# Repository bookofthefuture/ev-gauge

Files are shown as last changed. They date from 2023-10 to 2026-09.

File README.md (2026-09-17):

# ev-gauge
SoC, motor amps, motor/pack temp, 12V aux voltage, car mode and Zombieverter error
data over CANbus, on a single mode-aware display. For ESP32.

Copy `ev_gauge/secrets.h.example` to `ev_gauge/secrets.h` and fill in your home WiFi
SSID/password before flashing - the gauge runs its own `gaugedriver` AP and joins that
network at the same time, so OTA updates work both standalone and from your desk.

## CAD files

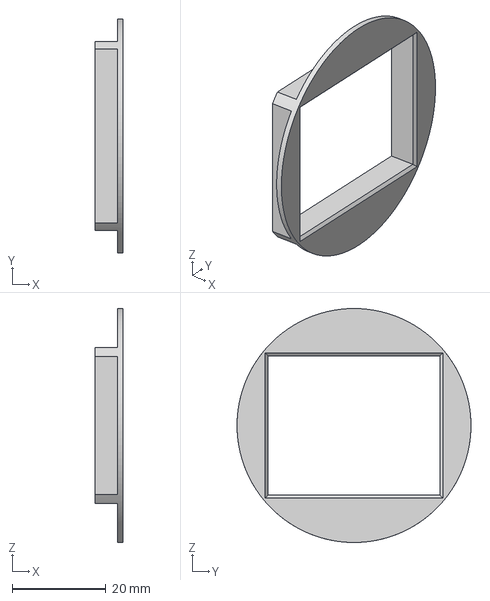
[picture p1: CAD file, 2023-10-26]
3D Files/z3_display_adaptor_front.3mf
6.00 x 50.0 x 50.0 mm

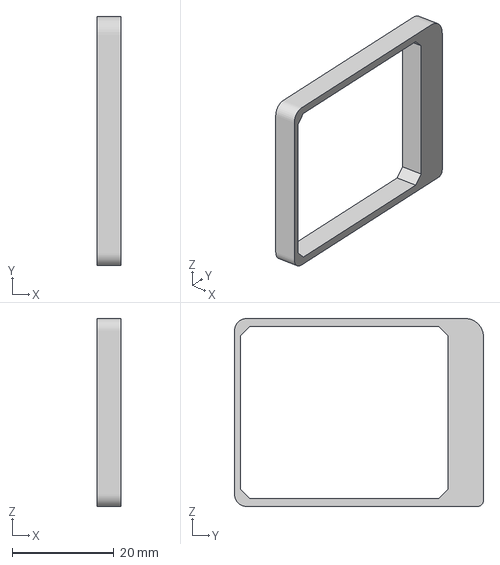
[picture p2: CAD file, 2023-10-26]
3D Files/z3_display_adaptor_rear.3mf
4.80 x 49.0 x 37.0 mm

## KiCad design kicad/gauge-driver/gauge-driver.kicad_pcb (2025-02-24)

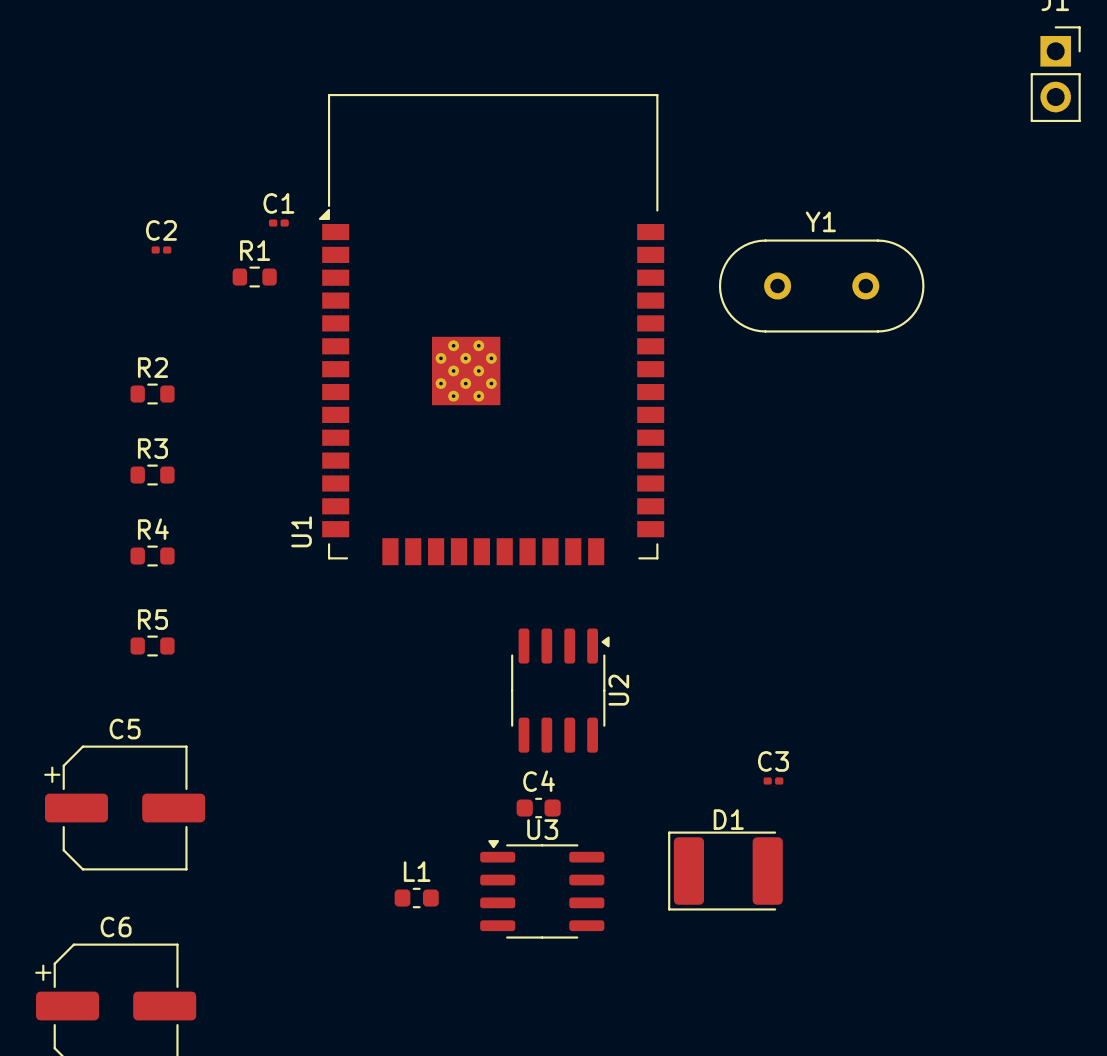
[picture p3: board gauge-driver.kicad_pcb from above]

Board: 2 copper layers, 18 parts (0 on the bottom side), 14 nets, no tracks yet.

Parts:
C1: 22uF; C_0201_0603Metric
C2: 0.1uF; C_0201_0603Metric
C3: 1uF; C_0201_0603Metric
C4: C; C_0603_1608Metric
C5, C6: C_Polarized; CP_Elec_6.3x3
D1: D_Schottky; D_2114_3652Metric
J1: Conn_01x02_Socket; PinSocket_1x02_P2.54mm_Vertical
L1: L; L_0603_1608Metric
R1: 10k; R_0603_1608Metric
R2, R3, R4: R; R_0603_1608Metric
R5: 10K; R_0603_1608Metric
U1: ESP32-WROOM-32E; ESP32-WROOM-32D
U2: SN65HVD230; SOIC-8_3.9x4.9mm_P1.27mm
U3: LM2675M-3.3; SOIC-8_3.9x4.9mm_P1.27mm
Y1: Crystal; Crystal_HC18-U_Vertical

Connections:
/3v3: C1.1, C2.1, R1.1, U1.2 (VDD)
/CAN0_RXD: U1.24 (IO2), U2.4 (R)
/CAN0_TXD: U1.23 (IO15), U2.1 (D)
/Vin_12V: C5.1, U3.7 (VIN)
/Vout_3v3: C6.1, L1.2, U3.4 (FB)
GND: C1.2, C2.2, C3.2, C5.2, C6.2, D1.2 (A), R2.2, R3.2, R4.1, R4.2, R5.2, U1.1 (GND), U1.15 (GND), U1.38 (GND), U1.39 (GND), U2.2 (GND), U3.6 (GND), Y1.1, Y1.2
unnamed: C4.2, D1.1 (K), L1.1, U3.8 (VSW)
unnamed: J1.1, U2.7 (CANH)
unnamed: J1.2, U2.6 (CANL)
unnamed: C3.1, R1.2, U1.3 (EN)
unnamed: R2.1, U1.8 (IO32)
unnamed: R3.1, U1.9 (IO33)
unnamed: R5.1, U2.8 (Rs)
unnamed: C4.1, U3.1 (CB)

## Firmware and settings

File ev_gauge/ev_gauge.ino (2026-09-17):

/* Canbus-powered information gauge for DIY EV. Designed for Adafruit 1.8in screen powered by ST7735 driver board.
 * Uses SN65HVD canbus transceiver with ESP32 onboard can
 * OTA updating for software in case the driver is buried in your dash
 * Reads SoC, pack temp, cell delta, motor current, motor temp, 12V aux voltage, car mode,
 * error codes and heater status from Zombieverter-mapped CAN signals (see the CanSignal
 * table and CAN_ID_HEATER below - these CAN IDs are placeholders and MUST be filled in with
 * your Zombieverter CAN map before flashing). The heater sits on its own CAN bus on the far
 * side of Zombieverter, so it's only visible here via Zombieverter's mapping too, same as
 * the battery/motor signals.
 * Display layout changes with car mode (On / Running / Charging) - see drawModeLayout().
 * Single physical display (tft1) - a second display was previously wired in software but
 * never actually installed, so that code has been removed.
*/

//Include libraries for display, OTA and can communications
#include <WiFi.h>
#include <WiFiClient.h>
#include <AsyncTCP.h> //
#include <ESPAsyncWebServer.h>
#include <Adafruit_GFX.h>    // Core graphics library https://github.com/adafruit/Adafruit-GFX-Library
#include <Adafruit_ST7735.h> // Hardware-specific library for ST7735 https://github.com/adafruit/Adafruit-ST7735-Library
#include <SPI.h>
#include <Arduino.h>
#include <esp32_can.h> // ESP32 native can library
#include <ElegantOTA.h> //Note: uses library in Async mode. Check documentation here: https://docs.elegantota.pro/async-mode/. Modification needed to library for this to work.
#include <SPIFFS.h>
#include <SPIFFS_ImageReader.h> // https://github.com/lucadentella/SPIFFS_ImageReader
#include <TaskScheduler.h> // https://github.com/arkhipenko/TaskScheduler
#include <math.h>

// Image reader
SPIFFS_ImageReader reader;

//#define DEBUG

// OTA CONFIG
const char* ssid = "gaugedriver"; // always-on AP, used as a fallback when not on HOME_WIFI_SSID
const char* password = "123456789";
#include "secrets.h" // HOME_WIFI_SSID / HOME_WIFI_PASSWORD - gitignored, see secrets.h.example

unsigned long ota_progress_millis = 0;

// HEATER DATA
bool hvPresent = false;
bool heater_enabled = false;
bool heating = false;

unsigned char heater_temp = 0;
unsigned char heater_target = 0;
unsigned long heaterTargetChangedAt = 0;

// Web interface
AsyncWebServer server(80);

// Include fonts for display
#include <Fonts/FreeSansBold12pt7b.h>
#include <Fonts/FreeSansBold18pt7b.h>
#include <Fonts/FreeSansBold24pt7b.h>
#include "ev_diy_font.h"


// Configure i2c pins for display - 30 pin layout
// Note change of layout to make wiring simpler

//BLK (backlight) connect to 3v3 output
//3v3
//GND
#define TFT_RST        25
#define TFT_SDA        26
#define TFT_SCL        27
#define TFT_DC         33
#define TFT_1_CS       14
#define TFT_1_BLK      19

// PWM for controlling display brightness
const int TFT_FREQ = 5000;
const int TFT_1_BLK_CHAN = 0;
const int RESOLUTION = 8;

//TFT CONFIG
Adafruit_ST7735 tft1 = Adafruit_ST7735(TFT_1_CS, TFT_DC, TFT_SDA, TFT_SCL, TFT_RST);

// Configure CAN TX/RX Pins
#define CAN_RX GPIO_NUM_13
#define CAN_TX GPIO_NUM_15

///////////////////////////////////////////////// ZOMBIEVERTER SIGNAL MAP ////////////////////////////////////////////////////////////
// CAN IDs below are PLACEHOLDERS - replace with the real IDs/offsets from your Zombieverter
// CAN map before flashing. Several of these may end up sharing a single frame once the real
// map is known, in which case they can share one CAN0.watchFor()/callback instead of one each.

struct CanSignal {
  uint32_t id;         // CAN ID this signal is mapped to on the Zombieverter - TODO fill in
  uint8_t  byteOffset;  // first data byte of the signal within the frame
  uint8_t  length;      // 1 or 2 bytes
  bool     isSigned;
  float    scale;       // physical value = raw * scale
};

CanSignal SIG_SOC        = { 0x500, 0, 2, false, 1.0 };   // % , 0-100
CanSignal SIG_PACK_TEMP  = { 0x501, 0, 2, true,  0.1 };   // deg C
CanSignal SIG_CELL_DELTA = { 0x502, 0, 2, false, 1.0 };   // mV
CanSignal SIG_MOTOR_AMPS = { 0x503, 0, 2, true,  1.0 };   // A, DC/pack current, signed (+ traction / - regen).
                                                            // Also reused (sign-inverted) for the Charging-mode
                                                            // charge-current readout - there's no separate charger
                                                            // CAN source any more, see drawChargeCurrent().
CanSignal SIG_MOTOR_TEMP = { 0x504, 0, 1, true,  1.0 };   // deg C
CanSignal SIG_AUX_VOLTS  = { 0x505, 0, 1, false, 0.1 };   // V, 12V aux battery
CanSignal SIG_CAR_MODE   = { 0x506, 0, 1, false, 1.0 };   // enum: 0=On 1=Running 2=Charging
CanSignal SIG_ERROR_CODE = { 0x507, 0, 2, false, 1.0 };   // bitmask of active Zombieverter errors

// The heater controller lives on the heater's own CAN bus, on the far side of Zombieverter -
// it's only visible here once Zombieverter forwards/maps it onto an ID on the main bus, so
// this is a placeholder like the signals above, not a direct read. Assumed to keep the same
// 8-byte layout as before (byte0 HV present, byte1 enabled, byte2 heating active, byte3
// actual water temp, byte4 target water temp) - adjust heater_can_proc() if Zombieverter
// remaps the individual fields instead of forwarding the whole frame.
const uint32_t CAN_ID_HEATER  = 0x508; // TODO Zombieverter-mapped ID for the heater status frame

// Thresholds for exception-only alerting while Running - tune once real signal ranges are known
const float PACK_TEMP_WARN_C  = 45.0;
const int   CELL_DELTA_WARN_MV = 50;
const int   MOTOR_TEMP_WARN_C = 90;
const int   MAX_MOTOR_AMPS    = 400; // full-scale for the amps gauge

///////////////////////////////////////////////// CAR MODE / DISPLAY STATE ////////////////////////////////////////////////////////////

enum CarMode { MODE_ON, MODE_RUNNING, MODE_CHARGING };
CarMode currentMode = MODE_ON;
bool modeChanged = true; // force initial layout draw

// Dirty flags - set by CAN callbacks, cleared by the render task once drawn
enum {
  DIRTY_SOC        = 1 << 0,
  DIRTY_PACKTEMP   = 1 << 1,
  DIRTY_DELTA      = 1 << 2,
  DIRTY_AMPS       = 1 << 3,
  DIRTY_MOTORTEMP  = 1 << 4,
  DIRTY_AUX        = 1 << 5,
  DIRTY_ERROR      = 1 << 6,
  DIRTY_HEATER     = 1 << 7,
};
volatile uint16_t dirtyFlags = 0;

// Live values, updated only by CAN callbacks, drawn only by the render task
volatile int   soc        = -1;   // -1 = unknown / not yet received
volatile float packTemp   = NAN;
volatile int   cellDelta  = -1;
volatile int   motorAmps  = 0;
volatile int   motorTempC = 0;
volatile float auxVolts   = 0;
volatile uint16_t errorCode = 0;

// Task Scheduling - drives the render pass so all TFT drawing happens from one
// consistent context instead of from inside CAN RX callbacks.
void renderTask();

Task renderTick(50, -1, &renderTask); // 50ms -> 20Hz, smooth enough for the amps gauge

Scheduler runner;

void setup() {

  #ifdef DEBUG
    Serial.begin(115200);
    Serial.print(millis());
    Serial.print("\t");
    Serial.println("In setup");
  #endif

  // Task scheduler
  runner.init();

  runner.addTask(renderTick);
  renderTick.enable();

  pinMode(TFT_RST, OUTPUT);

  // initialize SPIFFS
  if(!SPIFFS.begin()) {
    Serial.println("SPIFFS initialisation failed!");
    while (1);
  }

  // Initialise 1.8" TFT screen:
  tft1.initR(INITR_BLACKTAB);      // Init ST7735S chip, black tab

  Serial.print(millis());
  Serial.print("\t");
  Serial.println("TFT Init complete");

  // Setup backlight and set to black
  ledcSetup(TFT_1_BLK_CHAN, TFT_FREQ, RESOLUTION);
  ledcAttachPin(TFT_1_BLK, TFT_1_BLK_CHAN);
  ledcWrite(TFT_1_BLK_CHAN, 0);

  Serial.print(millis());
  Serial.print("\t");
  Serial.println("Backlight prep complete");

  reader.drawBMP("/launch.bmp", tft1, 0, 0);

  Serial.print(millis());
  Serial.print("\t");
  Serial.println("Logo drawn");

  backlight_ramp_up();

  Serial.print(millis());
  Serial.print("\t");
  Serial.println("Backlight ramp complete");

  backlight_ramp_down();

  tft1.setTextWrap(false);
  tft1.setRotation(0); // flipped 180 from the original - display sits upside-down relative to this in the car
  tft1.fillScreen(ST77XX_BLACK);
  #ifdef DEBUG
    Serial.print(millis());
    Serial.print("\t");
    Serial.println("Erased Screen");
  #endif

  backlight_ramp_up();

  // Draw the initial (mode = On) layout before any CAN data has arrived
  drawModeLayout(currentMode);
  modeChanged = false;
  dirtyFlags = 0xFFFF;

  // Initialise CANBus
  #ifdef DEBUG
    Serial.println("Initializing CANBus...");
  #endif
  CAN0.setCANPins(CAN_RX, CAN_TX);
  CAN0.begin(500000);

  // Set up can filters for target IDs
  CAN0.watchFor(CAN_ID_HEATER, 0xFFF);
  CAN0.watchFor(SIG_SOC.id, 0xFFF);
  CAN0.watchFor(SIG_PACK_TEMP.id, 0xFFF);
  CAN0.watchFor(SIG_CELL_DELTA.id, 0xFFF);
  CAN0.watchFor(SIG_MOTOR_AMPS.id, 0xFFF);
  CAN0.watchFor(SIG_MOTOR_TEMP.id, 0xFFF);
  CAN0.watchFor(SIG_AUX_VOLTS.id, 0xFFF);
  CAN0.watchFor(SIG_CAR_MODE.id, 0xFFF);
  CAN0.watchFor(SIG_ERROR_CODE.id, 0xFFF);

  //CAN0.watchFor(); //then let everything else through anyway - enable for debugging

  // Set callbacks for target IDs - order must match the watchFor() calls above
  CAN0.setCallback(0, heater_can_proc);
  CAN0.setCallback(1, soc_can_proc);
  CAN0.setCallback(2, packTemp_can_proc);
  CAN0.setCallback(3, cellDelta_can_proc);
  CAN0.setCallback(4, motorAmps_can_proc);
  CAN0.setCallback(5, motorTemp_can_proc);
  CAN0.setCallback(6, auxVolts_can_proc);
  CAN0.setCallback(7, carMode_can_proc);
  CAN0.setCallback(8, error_can_proc);

  // Run AP and station simultaneously: the "gaugedriver" AP is always reachable for OTA,
  // and the ESP32 also tries to join HOME_WIFI_SSID in the background so the gauge is
  // reachable on the home network without needing to connect to the car's own AP first.
  WiFi.mode(WIFI_AP_STA);
  WiFi.softAP(ssid, password);
  WiFi.begin(HOME_WIFI_SSID, HOME_WIFI_PASSWORD);
  Serial.println("");

  server.on("/", HTTP_GET, [](AsyncWebServerRequest *request) {
    request->send(200, "text/plain", "Gauge Driver OTA Interface");
  });

  ElegantOTA.begin(&server);    // Start ElegantOTA
  // ElegantOTA callbacks
  ElegantOTA.onStart(onOTAStart);
  ElegantOTA.onProgress(onOTAProgress);
  ElegantOTA.onEnd(onOTAEnd);

  server.begin();
  #ifdef DEBUG
    Serial.println("HTTP server started");
  #endif
  delay(4000);

  #ifdef DEBUG
    Serial.print(millis());
    Serial.print("\t");
    Serial.println("Ready ...!");
  #endif
}

void loop() {
  runner.execute();
  ElegantOTA.loop();
}

///////////////////////////////////////////////// PRINTFRAME ////////////////////////////////////////////////////////////


void printFrame(CAN_FRAME *message)
  {
    Serial.print(message->id, HEX);
    if (message->extended) Serial.print(" X ");
    else Serial.print(" S ");
    Serial.print(message->length, DEC);
    Serial.print(" ");
    for (int i = 0; i < message->length; i++) {
      Serial.print(message->data.byte[i], HEX);
      Serial.print(" ");
    }
    Serial.println();
  }

///////////////////////////////////////////////// SIGNAL DECODE ////////////////////////////////////////////////////////////

// Generic decoder for a Zombieverter-mapped signal: little-endian, 1 or 2 bytes, optionally
// signed, scaled to a physical value. Replaces the hand-rolled byte-shift decoding that used
// to be duplicated in every CAN callback.
float decodeSignal(const CanSignal &sig, CAN_FRAME *message) {
  long raw = message->data.byte[sig.byteOffset];
  if (sig.length == 2) {
    raw |= ((long)message->data.byte[sig.byteOffset + 1]) << 8;
  }
  if (sig.isSigned) {
    long signBit = 1L << (sig.length * 8 - 1);
    if (raw & signBit) raw -= (signBit << 1);
  }
  return raw * sig.scale;
}

///////////////////////////////////////////////// CAN CALLBACKS (data only, no drawing) //////////////////////////////////

void heater_can_proc(CAN_FRAME *message) {
  #ifdef DEBUG
    printFrame(message);
  #endif

  static bool prevEnabled = false, prevHeating = false;
  bool changed = false;

  hvPresent = (message->data.byte[0] == 0);      // HV present at heater
  heater_enabled = (message->data.byte[1] > 0);  // Heater enabled
  heating = (message->data.byte[2] > 0);         // Heating is active

  if (heater_enabled != prevEnabled || heating != prevHeating) {
    prevEnabled = heater_enabled;
    prevHeating = heating;
    changed = true;
  }

  if (message->data.byte[4] != heater_target) {
    heater_target = message->data.byte[4];
    heaterTargetChangedAt = millis(); // show the new target for a short delay, then fall back to actual temp
    changed = true;
  }

  if (message->data.byte[3] != heater_temp) {
    heater_temp = message->data.byte[3];
    changed = true;
  }

  if (changed) dirtyFlags |= DIRTY_HEATER;
}

void soc_can_proc(CAN_FRAME *message) {
  #ifdef DEBUG
    printFrame(message);
  #endif
  int v = (int)decodeSignal(SIG_SOC, message);
  if (v != soc) { soc = v; dirtyFlags |= DIRTY_SOC; }
}

void packTemp_can_proc(CAN_FRAME *message) {
  #ifdef DEBUG
    printFrame(message);
  #endif
  float v = decodeSignal(SIG_PACK_TEMP, message);
  if (v != packTemp) { packTemp = v; dirtyFlags |= DIRTY_PACKTEMP; }
}

void cellDelta_can_proc(CAN_FRAME *message) {
  #ifdef DEBUG
    printFrame(message);
  #endif
  int v = (int)decodeSignal(SIG_CELL_DELTA, message);
  if (v != cellDelta) { cellDelta = v; dirtyFlags |= DIRTY_DELTA; }
}

void motorAmps_can_proc(CAN_FRAME *message) {
  #ifdef DEBUG
    printFrame(message);
  #endif
  int v = (int)decodeSignal(SIG_MOTOR_AMPS, message);
  if (v != motorAmps) { motorAmps = v; dirtyFlags |= DIRTY_AMPS; }
}

void motorTemp_can_proc(CAN_FRAME *message) {
  #ifdef DEBUG
    printFrame(message);
  #endif
  int v = (int)decodeSignal(SIG_MOTOR_TEMP, message);
  if (v != motorTempC) { motorTempC = v; dirtyFlags |= DIRTY_MOTORTEMP; }
}

void auxVolts_can_proc(CAN_FRAME *message) {
  #ifdef DEBUG
    printFrame(message);
  #endif
  float v = decodeSignal(SIG_AUX_VOLTS, message);
  if (v != auxVolts) { auxVolts = v; dirtyFlags |= DIRTY_AUX; }
}

void carMode_can_proc(CAN_FRAME *message) {
  #ifdef DEBUG
    printFrame(message);
  #endif
  int raw = (int)decodeSignal(SIG_CAR_MODE, message);
  CarMode m = (raw == 2) ? MODE_CHARGING : (raw == 1) ? MODE_RUNNING : MODE_ON;
  if (m != currentMode) {
    currentMode = m;
    modeChanged = true;
  }
}

void error_can_proc(CAN_FRAME *message) {
  #ifdef DEBUG
    printFrame(message);
  #endif
  uint16_t v = (uint16_t)decodeSignal(SIG_ERROR_CODE, message);
  if (v != errorCode) { errorCode = v; dirtyFlags |= DIRTY_ERROR; }
}

///////////////////////////////////////////////// RENDER TASK ////////////////////////////////////////////////////////////
// Runs on a steady timer via the scheduler - this is the only place that draws to tft1.
// CAN callbacks above only ever update state and dirty flags.

void renderTask() {
  if (modeChanged) {
    drawModeLayout(currentMode);
    modeChanged = false;
    dirtyFlags = 0xFFFF; // redraw every field relevant to the new layout
  }

  if (dirtyFlags & DIRTY_SOC) {
    drawSoc();
    dirtyFlags &= ~DIRTY_SOC;
  }

  switch (currentMode) {
    case MODE_RUNNING:
      // Heater is most worth seeing right here - it's the one thing besides SoC/amps that
      // stays permanently on screen; everything else (temps/delta/errors) is exception-only.
      if (dirtyFlags & DIRTY_AMPS) {
        drawAmpsGauge();
        dirtyFlags &= ~DIRTY_AMPS;
      }
      updateHeaterPanel(134);
      dirtyFlags &= ~(DIRTY_PACKTEMP | DIRTY_DELTA | DIRTY_MOTORTEMP | DIRTY_ERROR | DIRTY_AUX);
      drawExceptionBanner(); // only touches the screen when the alert state actually changes
      break;

    case MODE_CHARGING:
      if (dirtyFlags & DIRTY_AMPS) {
        drawChargeCurrent();
        dirtyFlags &= ~DIRTY_AMPS;
      }
      if (dirtyFlags & DIRTY_PACKTEMP) {
        drawPackTemp(128);
        dirtyFlags &= ~DIRTY_PACKTEMP;
      }
      updateHeaterPanel(156);
      dirtyFlags &= ~(DIRTY_DELTA | DIRTY_MOTORTEMP | DIRTY_ERROR | DIRTY_AUX);
      break;

    case MODE_ON:
    default:
      // No heater panel here - HV (and so the heater) is locked out until Running/Charging.
      if (dirtyFlags & DIRTY_AUX) {
        drawAuxVolts();
        dirtyFlags &= ~DIRTY_AUX;
      }
      if (dirtyFlags & DIRTY_PACKTEMP) {
        drawPackTemp(148);
        dirtyFlags &= ~DIRTY_PACKTEMP;
      }
      dirtyFlags &= ~(DIRTY_AMPS | DIRTY_DELTA | DIRTY_MOTORTEMP | DIRTY_ERROR | DIRTY_HEATER);
      break;
  }
}

///////////////////////////////////////////////// MODE LAYOUT ////////////////////////////////////////////////////////////

void drawModeLayout(CarMode mode) {
  tft1.fillScreen(ST77XX_BLACK);

  tft1.setFont();
  tft1.setTextSize(1);
  tft1.setCursor(4, 10);
  switch (mode) {
    case MODE_RUNNING:
      tft1.setTextColor(ST77XX_GREEN);
      tft1.print("RUNNING");
      break;
    case MODE_CHARGING:
      tft1.setTextColor(ST77XX_CYAN);
      tft1.print("CHARGING");
      break;
    case MODE_ON:
    default:
      tft1.setTextColor(ST77XX_WHITE);
      tft1.print("ON");
      break;
  }

  // SoC panel - shown in every mode
  tft1.drawRoundRect(2, 16, 124, 60, 5, ST77XX_WHITE);

  if (mode == MODE_RUNNING) {
    tft1.drawRect(6, 96, 116, 14, ST77XX_WHITE); // amps gauge border, filled by drawAmpsGauge()
    tft1.setFont(&ev_diy_font);
    tft1.drawChar(6, 134, 128, 0x9515, 0, 1); // heater icon, colour set by updateHeaterPanel()
  } else if (mode == MODE_CHARGING) {
    tft1.setFont(&ev_diy_font);
    tft1.drawChar(6, 100, 129, ST77XX_WHITE, 0, 1); // charge icon
    tft1.drawChar(6, 128, 130, ST77XX_WHITE, 0, 1); // pack temp icon
    tft1.drawChar(6, 156, 128, 0x9515, 0, 1); // heater icon, colour set by updateHeaterPanel() - heater only runs while Charging/Running
  } else { // MODE_ON
    tft1.setFont(&ev_diy_font);
    tft1.drawChar(6, 148, 130, ST77XX_WHITE, 0, 1); // pack temp icon
  }

  tft1.setFont(&ev_diy_font);
  tft1.setTextSize(1);
}

///////////////////////////////////////////////// FIELD RENDERERS ////////////////////////////////////////////////////////////

void drawSoc() {
  tft1.fillRect(4, 18, 120, 56, ST77XX_BLACK);
  tft1.setFont(&FreeSansBold24pt7b);
  tft1.setTextColor(ST77XX_WHITE);
  tft1.setCursor(14, 62);
  if (soc >= 0 && soc <= 100) {
    tft1.print(soc);
    tft1.print("%");
  } else {
    tft1.print("--");
  }
  tft1.setFont(&ev_diy_font);
}

void drawAmpsGauge() {
  const int gx = 6, gy = 96, gw = 116, gh = 14;
  const int cx = gx + gw / 2;

  // numeric readout above the bar - sits in the gap between the SoC box (ends y76) and
  // the bar (starts y96), never on top of either
  tft1.fillRect(gx, gy - 18, gw, 16, ST77XX_BLACK);
  tft1.setFont(&FreeSansBold12pt7b);
  tft1.setTextColor(ST77XX_WHITE);
  tft1.setCursor(gx, gy - 4);
  tft1.print(motorAmps);
  tft1.print("A");
  tft1.setFont(&ev_diy_font);

  // bar, centred on 0A - fills right for traction (+), left for regen (-)
  tft1.fillRect(gx + 1, gy + 1, gw - 2, gh - 2, ST77XX_BLACK);
  tft1.drawFastVLine(cx, gy, gh, ST77XX_WHITE);

  int clamped = constrain(motorAmps, -MAX_MOTOR_AMPS, MAX_MOTOR_AMPS);
  int fillW = map(abs(clamped), 0, MAX_MOTOR_AMPS, 0, gw / 2 - 2);
  uint16_t barColor = (clamped >= 0) ? ST77XX_GREEN : ST77XX_BLUE;
  if (fillW > 0) {
    if (clamped >= 0) {
      tft1.fillRect(cx + 1, gy + 2, fillW, gh - 4, barColor);
    } else {
      tft1.fillRect(cx - 1 - fillW, gy + 2, fillW, gh - 4, barColor);
    }
  }
}

void drawChargeCurrent() {
  // motorAmps is + traction / - regen; while charging the same DC current signal runs the
  // other way, so flip it here rather than show a confusing "-8A" while charging.
  int chargeAmps = -motorAmps;

  tft1.fillRect(36, 84, 84, 20, ST77XX_BLACK);
  tft1.setFont(&FreeSansBold12pt7b);
  tft1.setTextColor(chargeAmps > 0 ? ST77XX_GREEN : ST77XX_WHITE);
  tft1.setCursor(36, 100);
  tft1.print(chargeAmps);
  tft1.print("A");
  tft1.setFont(&ev_diy_font);
}

// baseline matches the pack-temp icon's y in drawModeLayout() for the current mode -
// On and Charging show it at different rows now that Charging also has a heater row.
void drawPackTemp(int baseline) {
  tft1.fillRect(36, baseline - 16, 84, 20, ST77XX_BLACK);
  tft1.setFont(&FreeSansBold12pt7b);
  tft1.setTextColor(!isnan(packTemp) && packTemp >= PACK_TEMP_WARN_C ? 0xFA80 : ST77XX_WHITE);
  tft1.setCursor(36, baseline);
  if (!isnan(packTemp)) {
    tft1.print(packTemp, 1);
    tft1.print("C");
  } else {
    tft1.print("--");
  }
  tft1.setFont(&ev_diy_font);
}

void drawAuxVolts() {
  tft1.fillRect(4, 80, 120, 16, ST77XX_BLACK);
  tft1.setFont();
  tft1.setTextSize(1);
  tft1.setTextColor(auxVolts > 0 && auxVolts < 11.5 ? ST77XX_RED : ST77XX_WHITE);
  tft1.setCursor(6, 90);
  tft1.print("12V: ");
  tft1.print(auxVolts, 1);
  tft1.print("V");
  tft1.setFont(&ev_diy_font);
}
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

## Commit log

2022-06-30 format, font, flashing
    removed constant reset to black to avoid flashing
    resized fonts
    tweaked layout
    moved all text into functions
    [ev_gauge.ino]
2023-10-21 added slimmed down version created for 38 pin esp32 dev module.
    Pared back graphics and added more controllability for pins
2023-10-21 Update ev_gauge_2023_v2.ino
    Changed pins for smaller esp32 layout and added line to prime reset switch, to avoid screen whiteout
2023-10-26 added 3d printing files
    [z3_display_adaptor_front.3mf, z3_display_adaptor_rear.3mf]
2023-10-28 Added pin options for 38 pin layout
2023-11-04 switched 30 pin can pins
    can't remember if I maybe transposed them and this is why can isn't working after OTA update
2023-11-06 switched back to 30 pin
    Need to create a config option for this
2023-11-06 Added selector for 38 or 30 pin board and tidied up
2023-11-13 added wire colours
    Sorry if you're using this - just for my own purposes
2024-01-14 Revert "added wire colours"
    This reverts commit f70837c6e81b463de035a88e7492f9e43f48d391.
2024-01-18 first pass at heater info
    added in new filters and functions to update heater info on single display
2024-01-19 added pre-canbus heating symbols
2024-01-19 dual gauge layout
    simplified wiring and standardised on 30 pin module, added in dual display controls
2024-02-26 Fixed can address for heater data
    also switched 'ERR' for '...' when soc over 100
2024-02-26 fixed can address for heater data
    also swapped 'err' for '...' when soc over 100
2024-12-17 added kicad files for hardware project
    [gauge-driver.kicad_pcb, gauge-driver.kicad_sch]
2024-12-20 Added cp2102
    [gauge-driver.kicad_pcb, gauge-driver.kicad_sch]
2024-12-22 updated cp2102 wiring
    [gauge-driver.kicad_sch]
2025-02-18 screwed up re-order
2025-02-18 Fixed re-ordering. Both screens now loading logo
    [gauge-driver.kicad_pcb, gauge-driver.kicad_sch]
2025-02-18 switched to taskscheduler
    moved functions for keeping display happy over to task scheduler and fixed some errors. tidied up code a bit.
2025-02-22 Moved CANbus pin to avoid upload issues
    No need to disconnect can transceiver when uploading now
2025-02-24 increased pwm frequency
2025-02-25 inverted displays - deleted old binary
    [ev_gauge.ino]
2025-03-02 switched to sending display data from heater driver not heater and reformatted display
2025-03-02 added custom icon font
    tweaked display to be tidier and show charging info
2025-03-08 fixed wrong char issues & tweaked font size for soc
    [ev_gauge.ino]
2025-03-09 rewrote heater_proc
2025-03-16 minor tweaks to fix soc_proc
    [ev_gauge.ino]
2025-03-16 rewrote heater_proc because it wasn't working
2026-09-17 Switch to Zombieverter CAN data, drop legacy dash spoofing, mode-aware display
    Removes the EML/ABS/rev-counter frame spoofing (eml/asc/eng_speed) that
    used to run every 10ms, and the unused second-screen code (tft2 was
    never physically installed). SoC, pack temp, cell delta, motor current,
    motor temp, 12V aux voltage, car mode, error codes and heater status now
    all come from Zombieverter-mapped CAN signals via a single decode table
    (CAN IDs are placeholders - TODO before flashing) instead of being
    hand-decoded from raw BMS/heater-controller frames.
    The display now changes layout with car mode (On/Running/Charging):
    Running keeps SoC, the motor-amps gauge and heater status permanently
    visibl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
    [ev_gauge.ino]
2026-09-23 Add blank KiCad project for twin round display board
    Ignore KiCad lock files, auto-backups and footprint cache.
    [ev-gauge-twin-round-display.kicad_pcb, ev-gauge-twin-round-display.kicad_sch]
2026-09-23 Flatten twin round display KiCad project into its folder
    Also commit the project settings KiCad wrote on first save.
    [ev-gauge-twin-round-display.kicad_pcb, ev-gauge-twin-round-display.kicad_sch]
2026-09-26 Add first-pass schematic for twin round display board
    ESP32-S3-MINI-1 with TCAN332 CAN transceiver, TPS54202 buck and
    AP2127K 3.3V LDO, USB-C, PC817 opto input, TVS/polyfuse protection
    and display/expansion headers. PCB layout not started.
    [ev-gauge-twin-round-display.kicad_sch]
